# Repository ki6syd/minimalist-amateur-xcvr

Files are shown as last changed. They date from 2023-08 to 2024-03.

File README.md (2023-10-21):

 # minimalist-amateur-xcvr

Annotations (1) (1)

The radio hardware and user interface communicate with this API: https://app.swaggerhub.com/apis-docs/KI6SYD_1/MAX-3B/1.0.2

See http://max-3b.ki6syd.com for instructions on assembling the hardware and building firmware, in addition to background on the radio. The GitHub project just contains design files and code.

Software in this project is licensed under the GPLv3 License. https://www.gnu.org/licenses/quick-guide-gplv3.html

Hardware in this project is licensed under the TAPR Open Hardware License. https://tapr.org/the-tapr-open-hardware-license/

This project redistributes Ace.js, Copyright (c) 2010, Ajax.org B.V.

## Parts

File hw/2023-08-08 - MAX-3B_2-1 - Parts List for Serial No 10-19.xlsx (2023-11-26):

Item # | *Designator | *Qty | *Mfg Part # | *Package/Footprint
1 | C9, C10, C18, C22, C23, C25, C27, C28, C30, C33, C36, C40, C41, C42, C44, C51, C55, C56, C57, C58, C59, C62, C66, C68, C69, C82, C92, C93, C94, C98, C107, C153, C169, C170, C171, C172 | 36 | CC0201KRX5R5BB104 | 0201
2 | C11, C12, C19, C20, C24, C26, C34, C35, C43, C49, C54, C79, C84, C87, C91, C108, C109, C173, C178, C181, C182 | 21 | C0402C105K8PACTU | 0402
3 | R22, R25, R38, R39, R41, R44, R45, R46, R47, R48, R64, R74, R84, R88, R89, R93, R100, R102, R103 | 19 | CRCW020110K0FKED | 0201
4 | Q6, Q7, Q8, Q9, Q10, Q11, Q12, Q13, Q14, Q15, Q16, Q18, Q27, Q28, Q29, Q30, Q31 | 17 | DMN313DLT-7 | SOT-416
5 | C2, C3, C7, C8, C15, C16, C131, C132, C133, C134, C135, C136 | 12 | CGA3E1X7R1E105K080AC | 0603
6 | C17, C29, C64, C76, C77, C78, C88, C89, C90, C101, C141, C156 | 12 | C0402C102J5GACTU | 0402
7 | C127, C130, C145, C146, C147, C148, C149, C150, C151, C152 | 10 | C0402C270F5GACTU | 0402
8 | D9, D10, D11, D12, D13, D14, D16, D17, D18, D19 | 10 | NSR0240V2T1G | SOD-523
9 | R1, R2, R3, R10, R13, R16, R49, R94, R107, R119 | 10 | CRCW04020000Z0ED | 0402
10 | R12, R20, R30, R32, R62, R67, R72, R120, R121 | 9 | CRCW04021K00FKTD | 0402
11 | C37, C45, C112, C115, C119, C122, C126, C129 | 8 | GRM0335C1E100JA01D | 0201
12 | Q19, Q20, Q21, Q22, Q23, Q24, Q25, Q26 | 8 | 2N7002H6327XTSA2 | SOT-23
13 | R4, R5, R11, R19, R35, R69, R70, R85 | 8 | RC0402FR-0749K9L | 0402
14 | R21, R66, R73, R87, R91, R99, R117, R118 | 8 | CRGCQ0402F100K | 0402
15 | R108, R109, R110, R111, R112, R113, R114, R115 | 8 | CRCW04021R00FNED | 0402
16 | R23, R40, R42, R55, R134, R135, R136 | 7 | ERJ-2RKF1000X | 0402
17 | R26, R27, R28, R29, R33, R58, R61 | 7 | CRCW04025K10FKED | 0402
18 | RL1, RL2, RL3, RL4, RL5, RL6, RL7, RL8 | 8 | IM03CGR | IM RELAY GW
19 | C159, C160, C163, C167, C168, C186 | 6 | C0603C361J5GACTU | 0603
20 | C138, C139, C143, C144, C158 | 5 | C0603X681J5GACTU | 0603
21 | R36, R37, R56, R57, R65 | 5 | CRCW04024K70FKEDC | 0402
22 | C13, C14, C21, C86 | 4 | 865090140001 | 4.3MMx4.3MM
23 | C52, C53, C60, C65 | 4 | C0402C101J5GACTU | 0402
24 | C99, C100, C104, C106 | 4 | GRM1555C1H220GA01D | 0402
25 | C113, C116, C179, C180 | 4 | C0603C151J5GACTU | 0603
26 | L2, L3, L14, L15 | 4 | BLM21RK102SN1D | 0805
27 | R17, R18, R59, R60 | 4 | RC0805FR-10100RL | 0805
28 | R24, R90, R105, R116 | 4 | CRCW02011K00FNED | 0201
29 | R68, R79, R80, R101 | 4 | CR0402-FX-3302GLF | 0402
30 | U14, U15, U16, U17 | 4 | TSV852IQ2T | 8-UFDFN (2x2)
31 | C38, C39, C67 | 3 | CC0805KKX5R8BB106 | 0805
32 | C46, C47, C48 | 3 | CGA2B3X7R1V103K050BB | 0402
33 | C161, C162, C165 | 3 | VJ0603A471JXAAC | 0603
34 | D2, D4, D5 | 3 | PMEG2020AEA,115 | SOD-323
35 | Q1, Q2, Q17 | 3 | SI7101DN-T1-GE3 | PowerPAK1212-8
36 | C4, C5 | 2 | EEE-1EA220WR | 5.5MMx5.5MM
37 | C31, C32 | 2 | GRM033R71C391KA01D | 0201
38 | C61, C140 | 2 | C0603C222J5GACTU | 0603
39 | C70, C81 | 2 | C0402C332K4RACTU | 0402
40 | C73, C137 | 2 | CGA2B3X7R1H473K050BB | 0402
41 | C74, C75 | 2 | C0402C222J3GACTU | 0402
42 | C103, C105 | 2 | JR300 | 3.5MMx3.1mm
43 | C120, C123 | 2 | 04025A680JAT2A | 0402
44 | C154, C155 | 2 | 06035A561FAT2A | 0603
45 | C164, C166 | 2 | VJ0603A221JXACW1BC | 0603
46 | D1, D3 | 2 | PMEG3050EP,115 | SOD-128
47 | D6, D15 | 2 | BZX84C4V7LT1G | SOT-23
48 | J4, J5 | 2 | SJ1-3524N | SJ1-35
49 | Q4, Q5 | 2 | SMMBT3904WT1G | SOT-323
50 | R34, R122 | 2 | CRGCQ0402F22K | 0402
51 | R75, R76 | 2 | CRCW040236K0FKED | 0402
52 | R77, R78 | 2 | CRCW040247K0FKEDHP | 0402
53 | R83, R104 | 2 | AC0402FR-072K2L | 0402
54 | R125, R126 | 2 | CR0402-FX-4020GLF | 0402
55 | U2, U3 | 2 | LT1965IDD-3.3#PBF | 8-WFDFN (3x3)
56 | U10, U11 | 2 | PCF8574DGVR | 20-TFSOP
57 | U12, U13 | 2 | SN74LVC2G53DCUR | 8-VFSOP
58 | X1, X2 | 2 | ABM8G-26.000MHZ-B4Y-T | 3225
59 | C1 | 1 | C0603C474K4RACTU | 0603
60 | C50 | 1 | GJM1555C1H5R6BB01D | 0402
61 | C71 | 1 | GCM155R71E333KA55D | 0402
62 | C72 | 1 | 0402ZC393KAT2A | 0402
63 | C80 | 1 | C0402C681K3RACTU | 0402
64 | C110 | 1 | VJ0402D150JXCAJ | 0402
65 | C117 | 1 | GJM1555C1H6R0WB01D | 0402
66 | C124 | 1 | GJM1555C1H3R0BB01D | 0402
67 | D8 | 1 | NSVBAT54SWT1G | SOT-323
68 | J1 | 1 | 0733910320 | RP-SMA
69 | J2 | 1 | 0022286020 | 2x0.1IN
70 | J3 | 1 | USB4085-GF-A | USB-C
71 | J10 | 1 | 733910083 | SMA
72 | L1 | 1 | 7447785004 | WE-PD-XS
73 | L4 | 1 | LQM21FN100M70L | 0805
74 | L7 | 1 | 74437324220 | WE-LHMI-4020
75 | Q3 | 1 | PMDPB70XP,115 | 6-UFDFN (2x2)
76 | R31 | 1 | ERJ-2RKF2401X | 0402
77 | R43 | 1 | CRCW020112K0FNED | 0201
78 | R71 | 1 | RC0402FR-0710RL | 0402
79 | R81 | 1 | ERJ-2GEJ754X | 0402
80 | R82 | 1 | CRGCQ0402F470R | 0402
81 | R86 | 1 | AC0402FR-07220KL | 0402
82 | R92 | 1 | 3361P-1-103GLF | 3361P
83 | S1 | 1 | KSS221GLFS | KSS22
84 | U1 | 1 | LT3971IDD-5#PBF | 10-WFDFN (3x3)
85 | U4 | 1 | CYPD3177-24LQXQ | 24-UFQFN (4x4)
86 | U5 | 1 | LMV321LICT | SC-70-5
87 | U6 | 1 | ESP8266EX | 32-VFQFN (5x5)
88 | U7 | 1 | CP2102N-A02-GQFN28 | 28-WFQFN (5x5)
89 | U8 | 1 | W25Q32JVSSIQ | 8-SOIC
90 | U9 | 1 | SI5351A-B-GT | 10-MSOP
91 | U18 | 1 | PGA-103+ | SOT-89
92 | U21 | 1 | SN74ACT245PWR | 20-TSSOP
93 | U24 | 1 | PAM8302AASCR | 8-MSOP

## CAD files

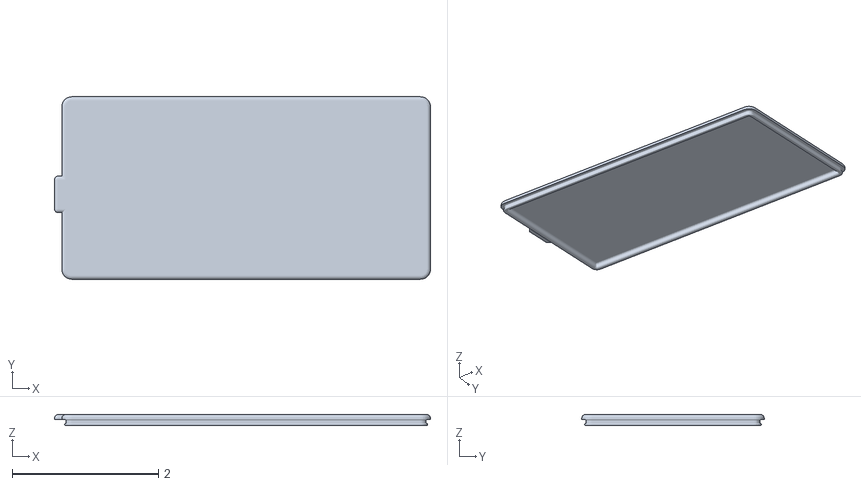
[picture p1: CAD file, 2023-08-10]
hw/3d printed case/2023-09-18 - MAX-3B Lid.stl
5.14 x 2.49 x 0.15

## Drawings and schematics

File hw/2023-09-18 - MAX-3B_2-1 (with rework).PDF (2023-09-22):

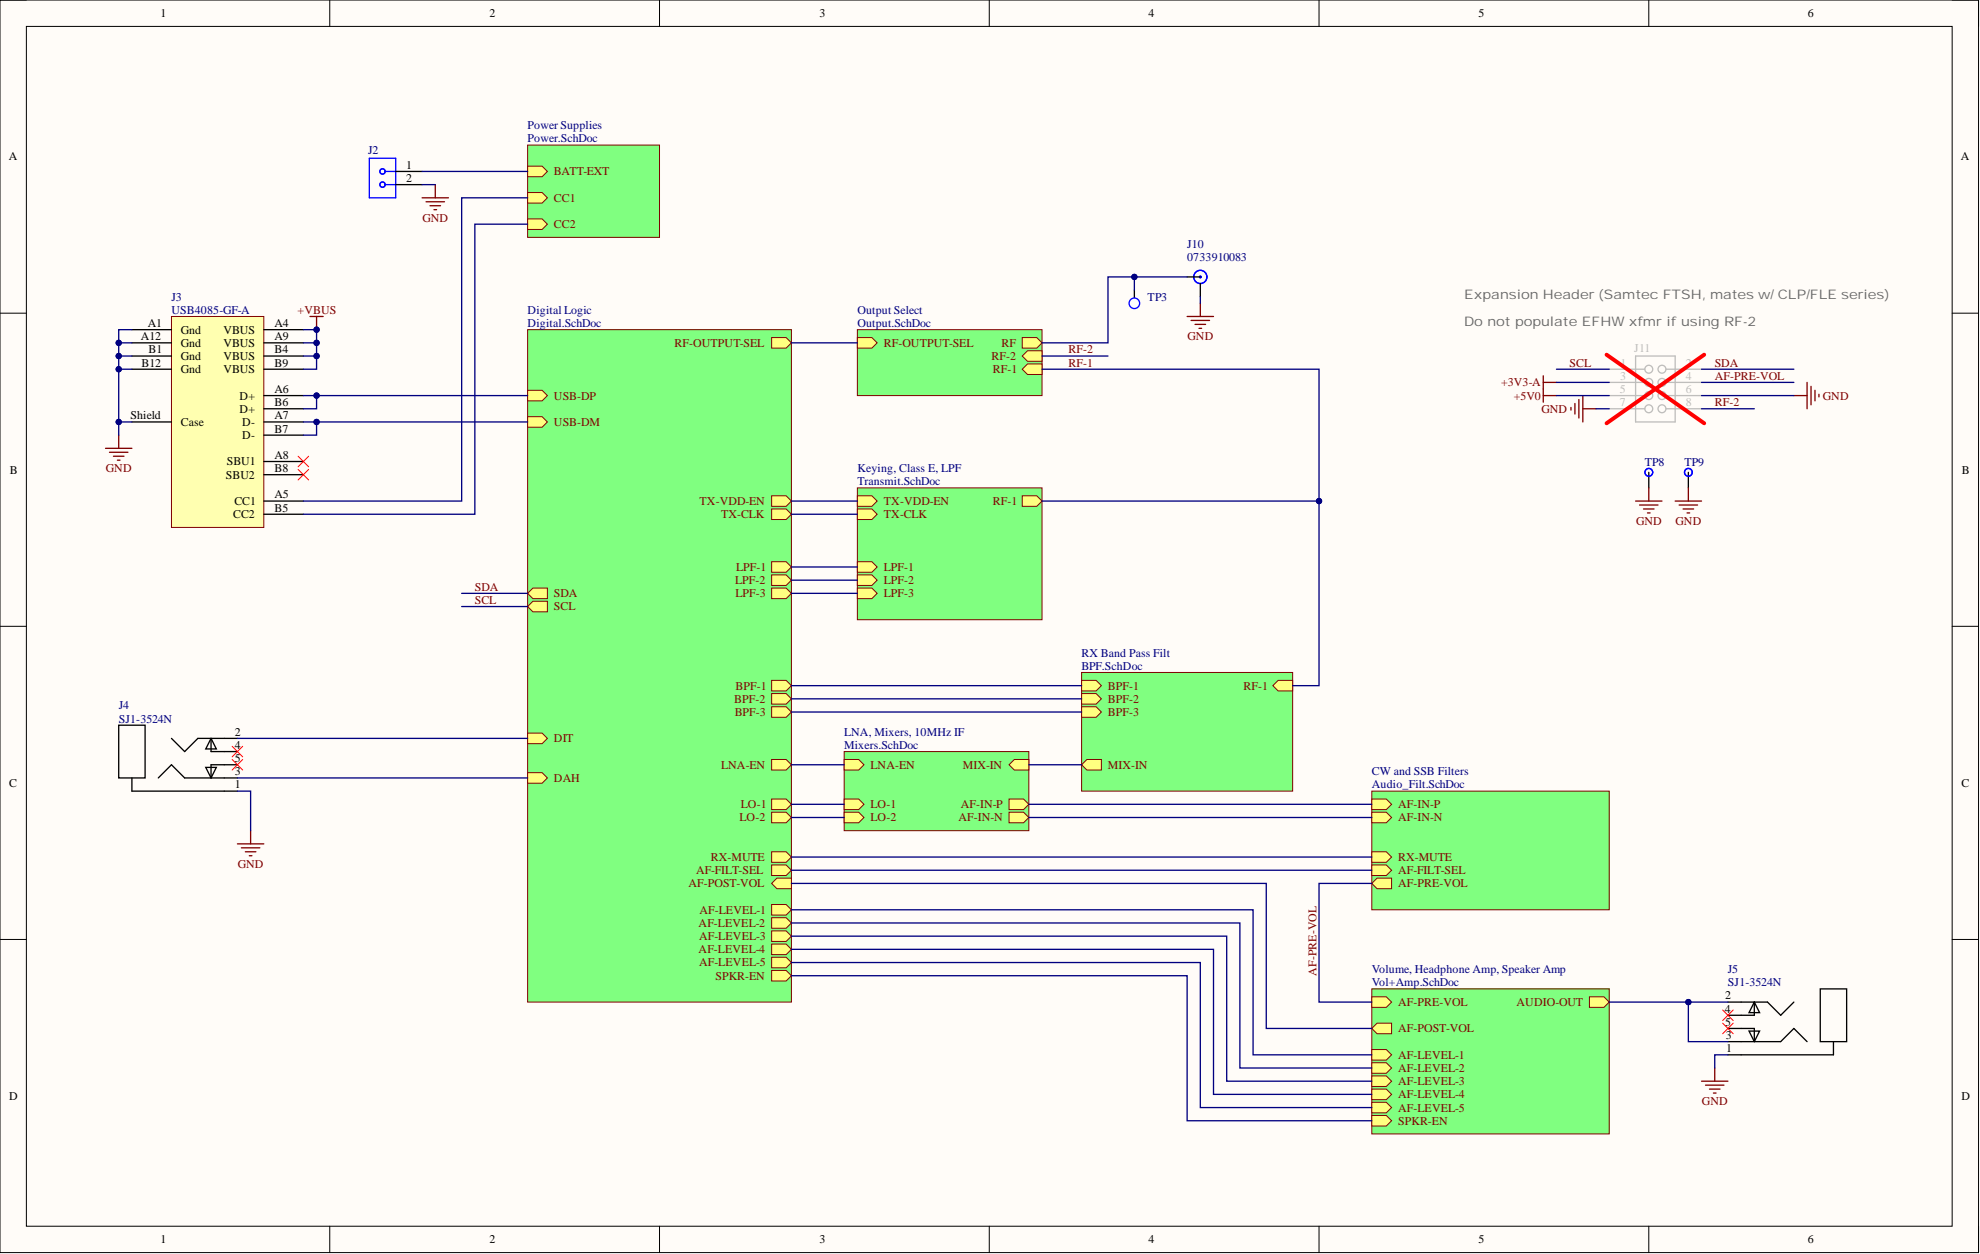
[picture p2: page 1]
Gnd B12; B7 Case Shield USB4085-GF-A J3; d SSB Fi; RX Ban; d Pas; BPF-2 LPF-1 LPF-2; 0MHz IF; wer Su; LPF-1 TX-V; LPF-2 LPF-3; g, Clas; t Selec; Expansion Header; Samtec FT; Amp, Speaker

Do not popula

te EFHW xfmr if using RF-2

AF-PRE-VOL

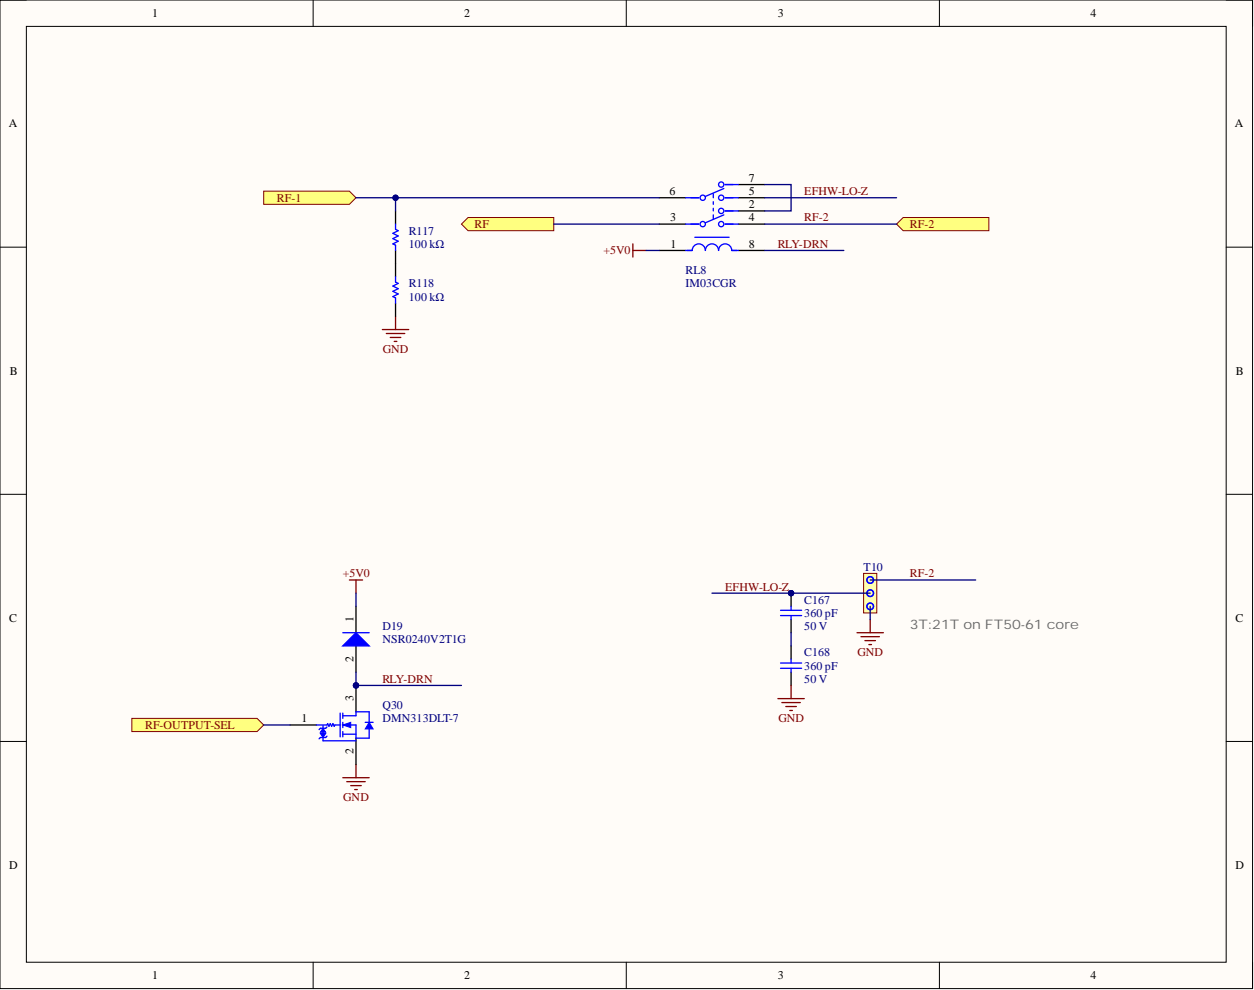
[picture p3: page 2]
RLY-DRN +5V0; 3T:21T on FT50-61 core

RF-OUTPUT-SEL

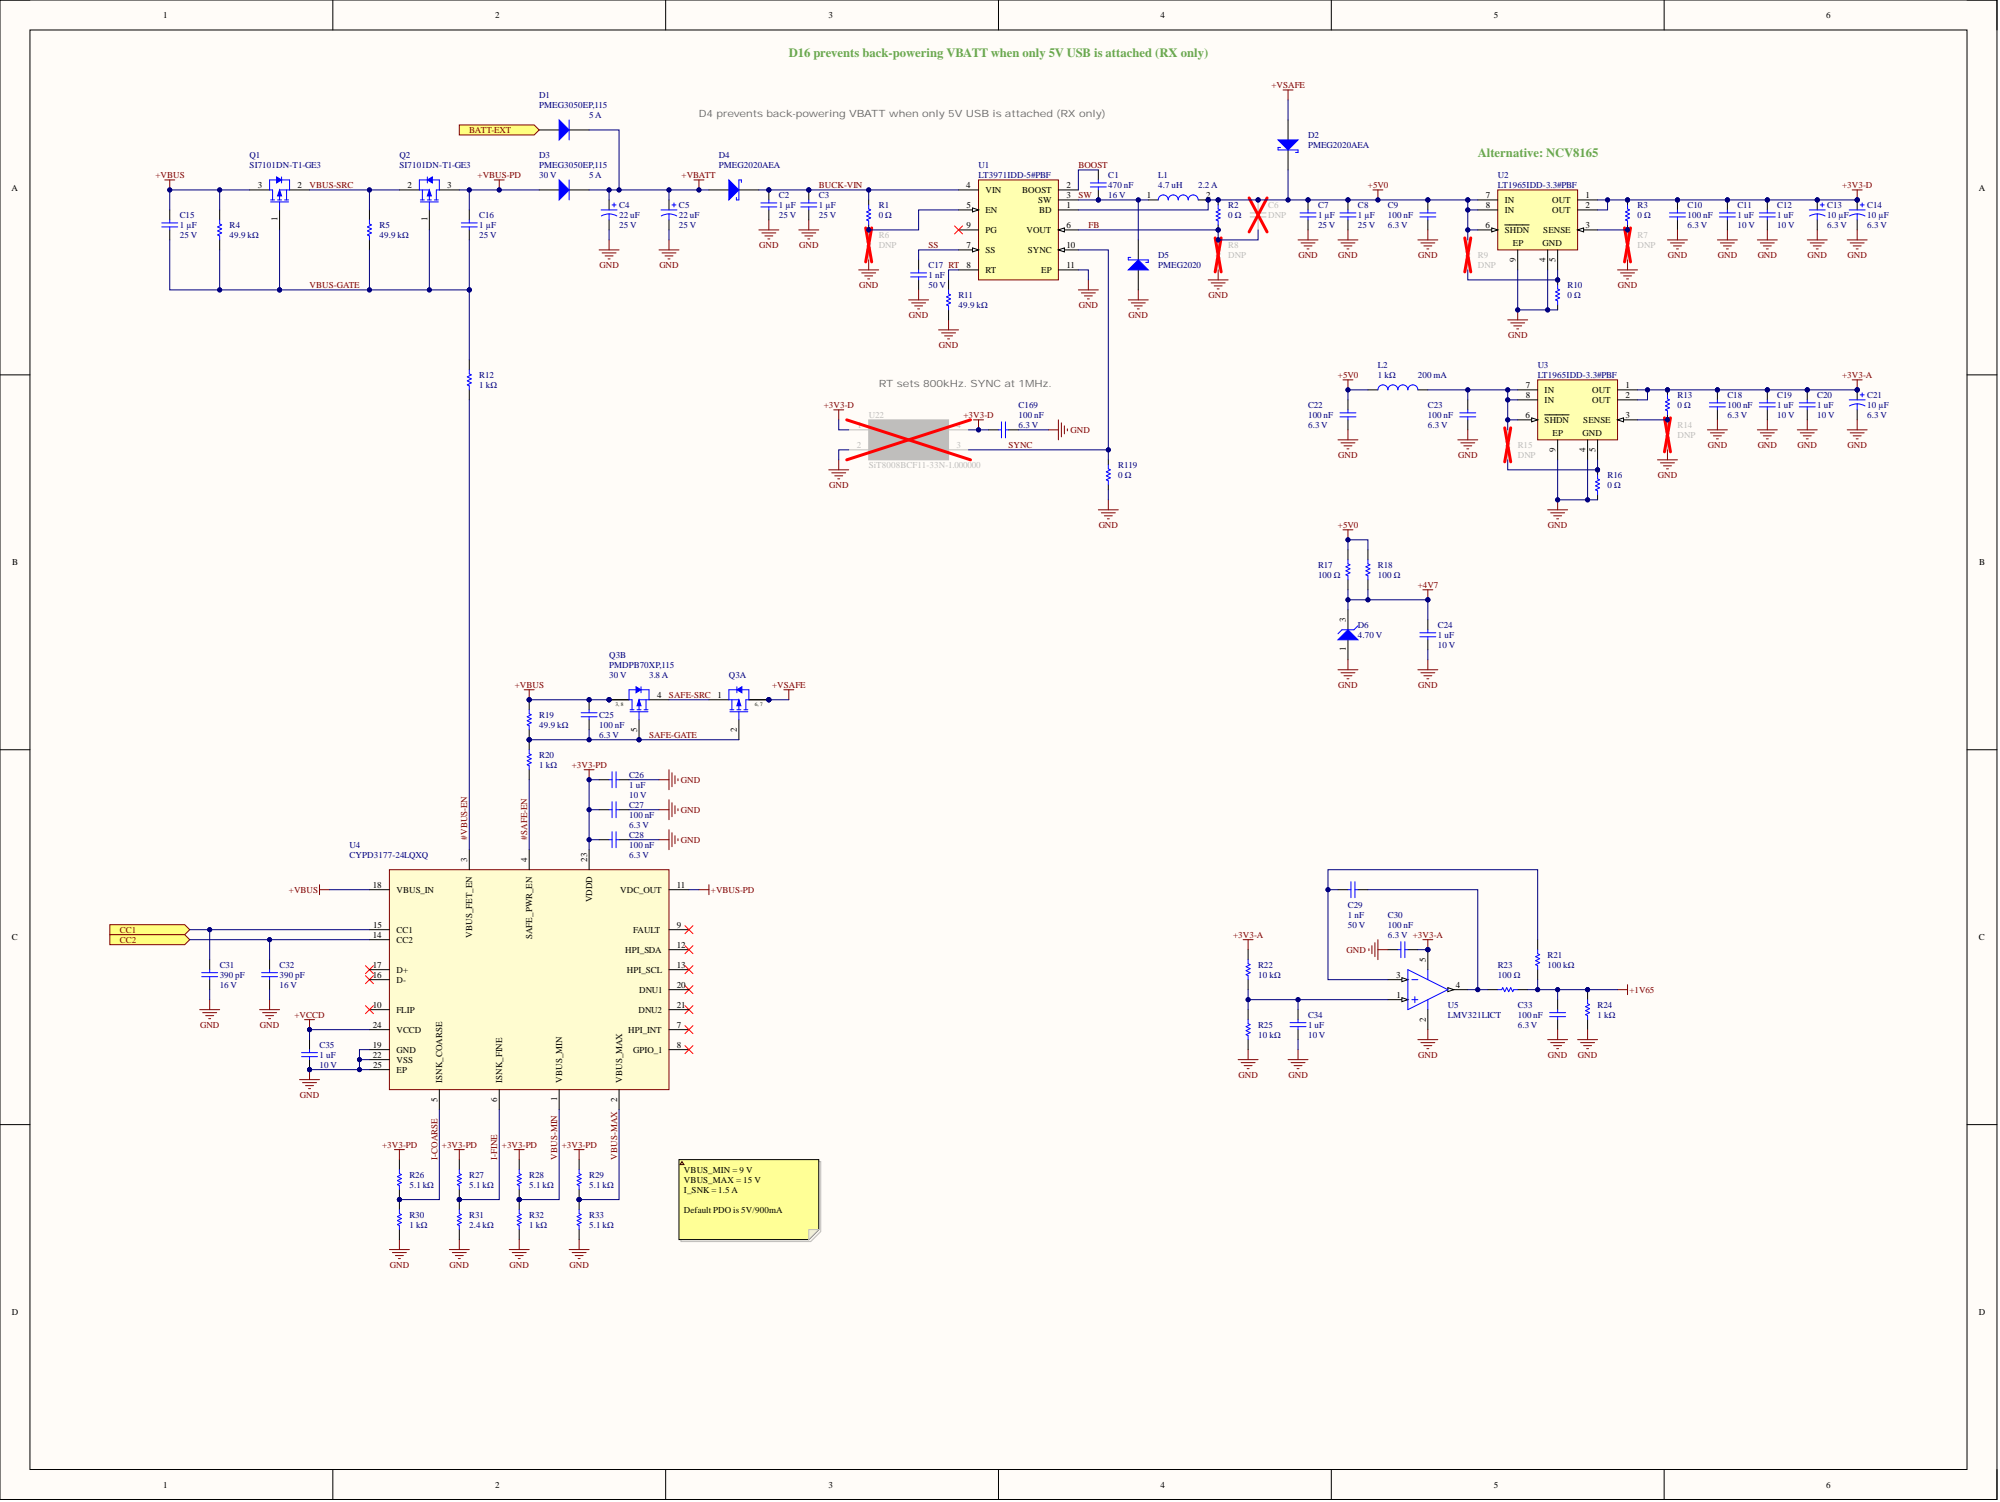
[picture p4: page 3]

D16 prevents back-powering VBATT when only 5V USB is attached (RX only)

D4 prevents back-powering VBATT when only 5V USB is attached (RX only)

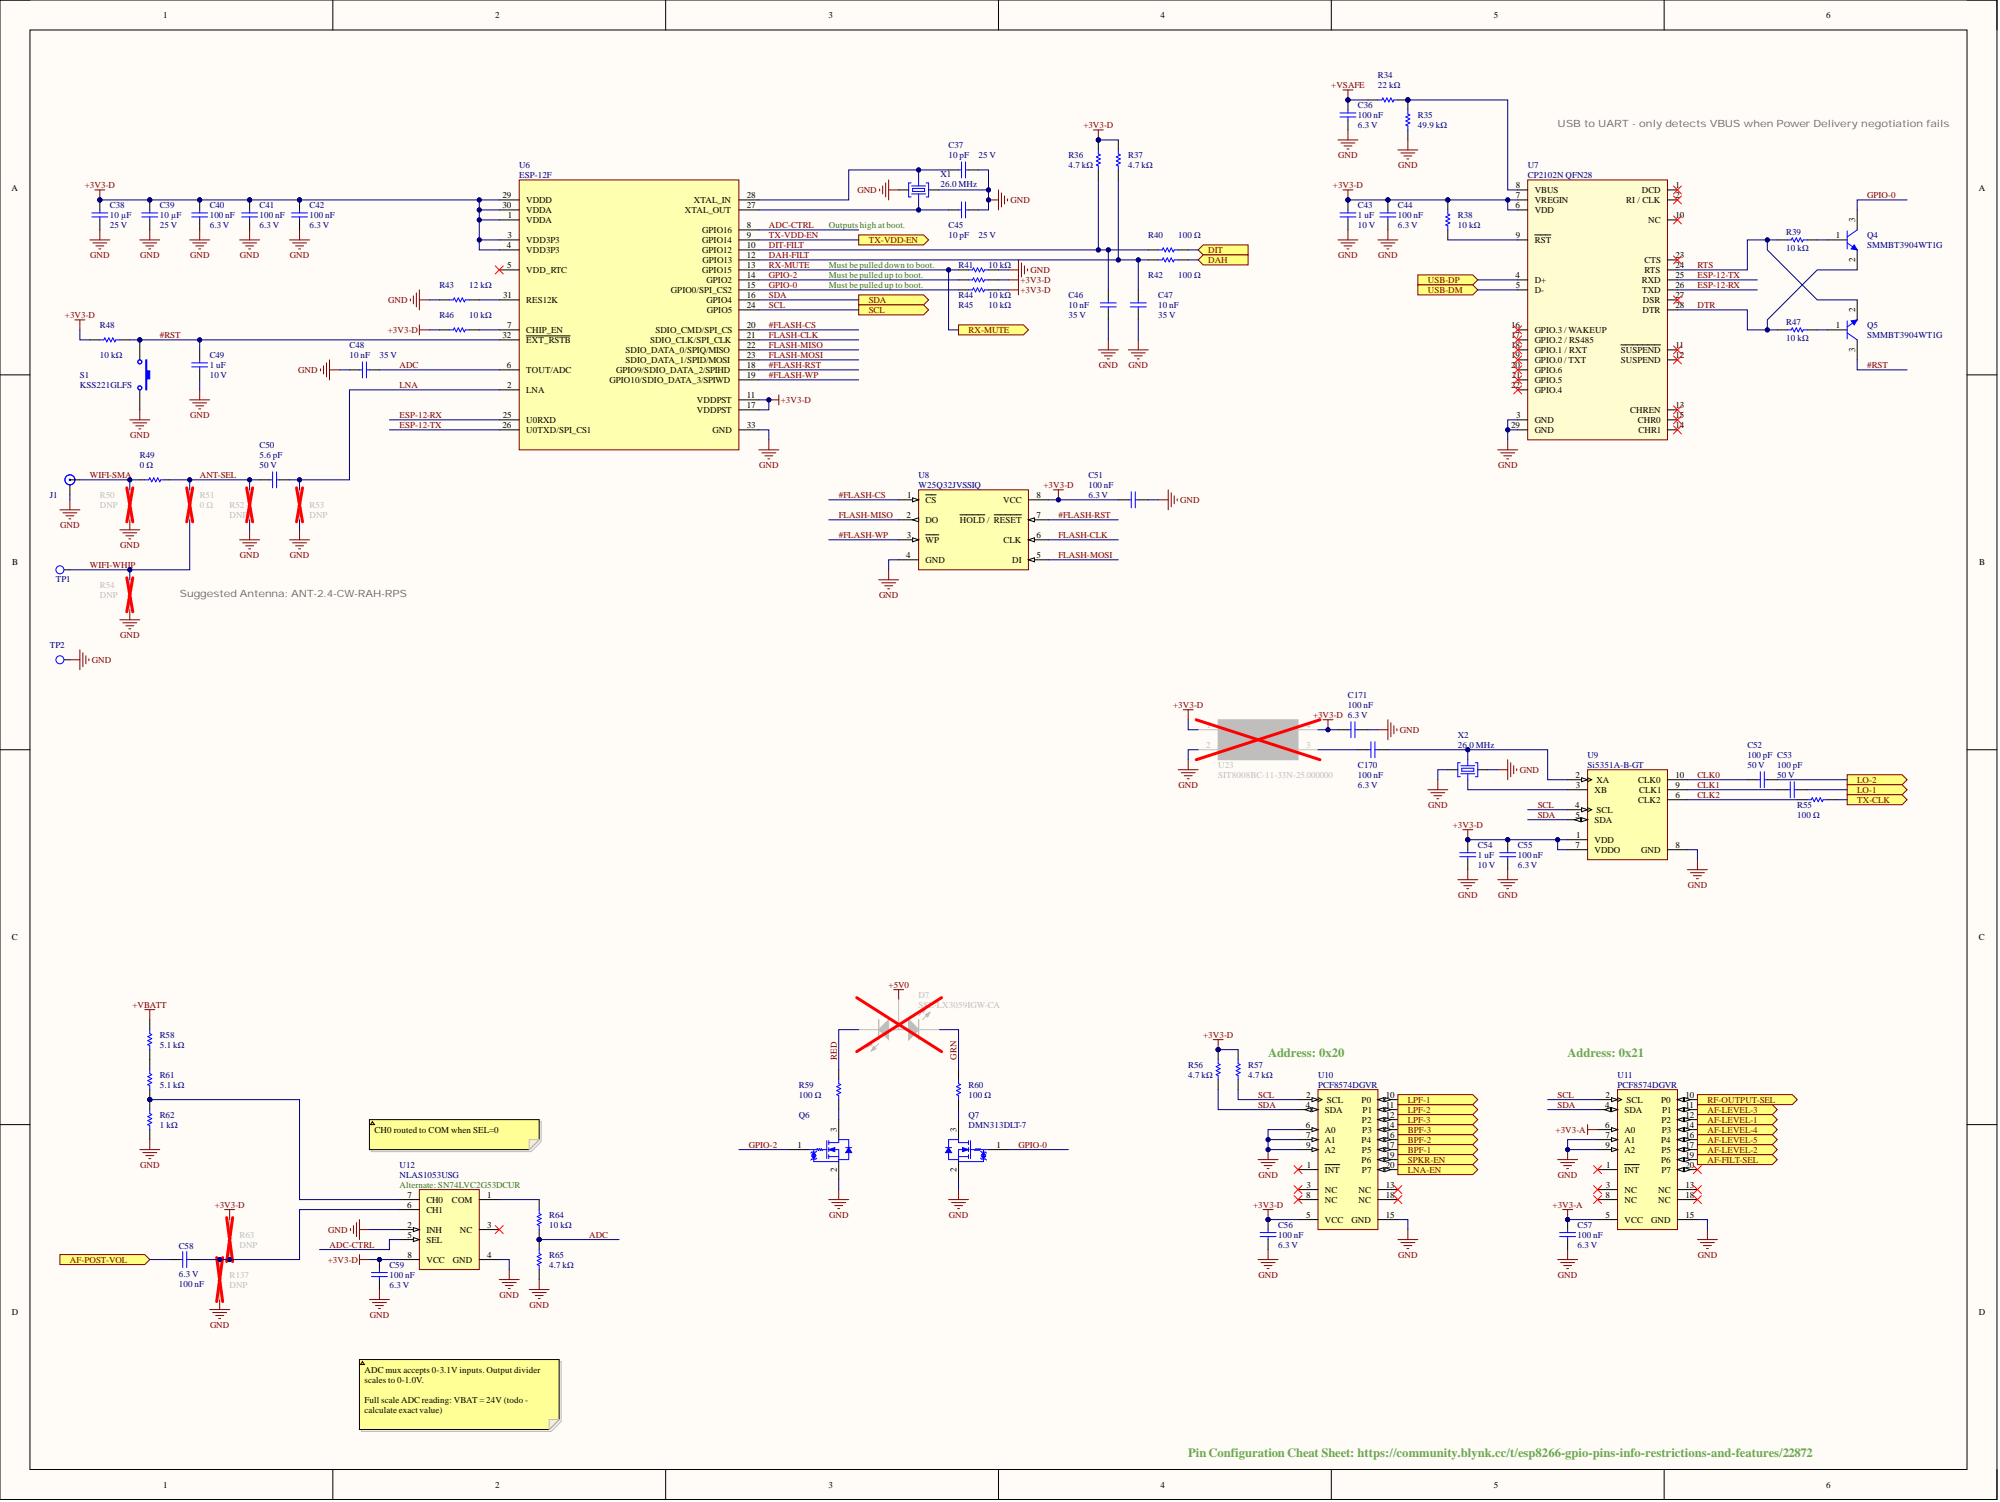
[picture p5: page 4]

USB to UART - only detects VBUS when Power Delivery negotiation fails

Must be pulled down to boot.
Must be pulled up to boot.

Suggested Antenna: ANT-2.4-CW-RAH-RPS

CH0 routed to COM when SEL=0

ADC mux accepts 0-3.1V inputs. Output divider
scales to 0-1.0V.

Full scale ADC reading: VBAT = 24V (todo -
calculate exact value)

Pin Configuration Cheat Sheet: https://community.blynk.cc/t/esp8266-gpio-pins-info-restrictions-and-features/22872

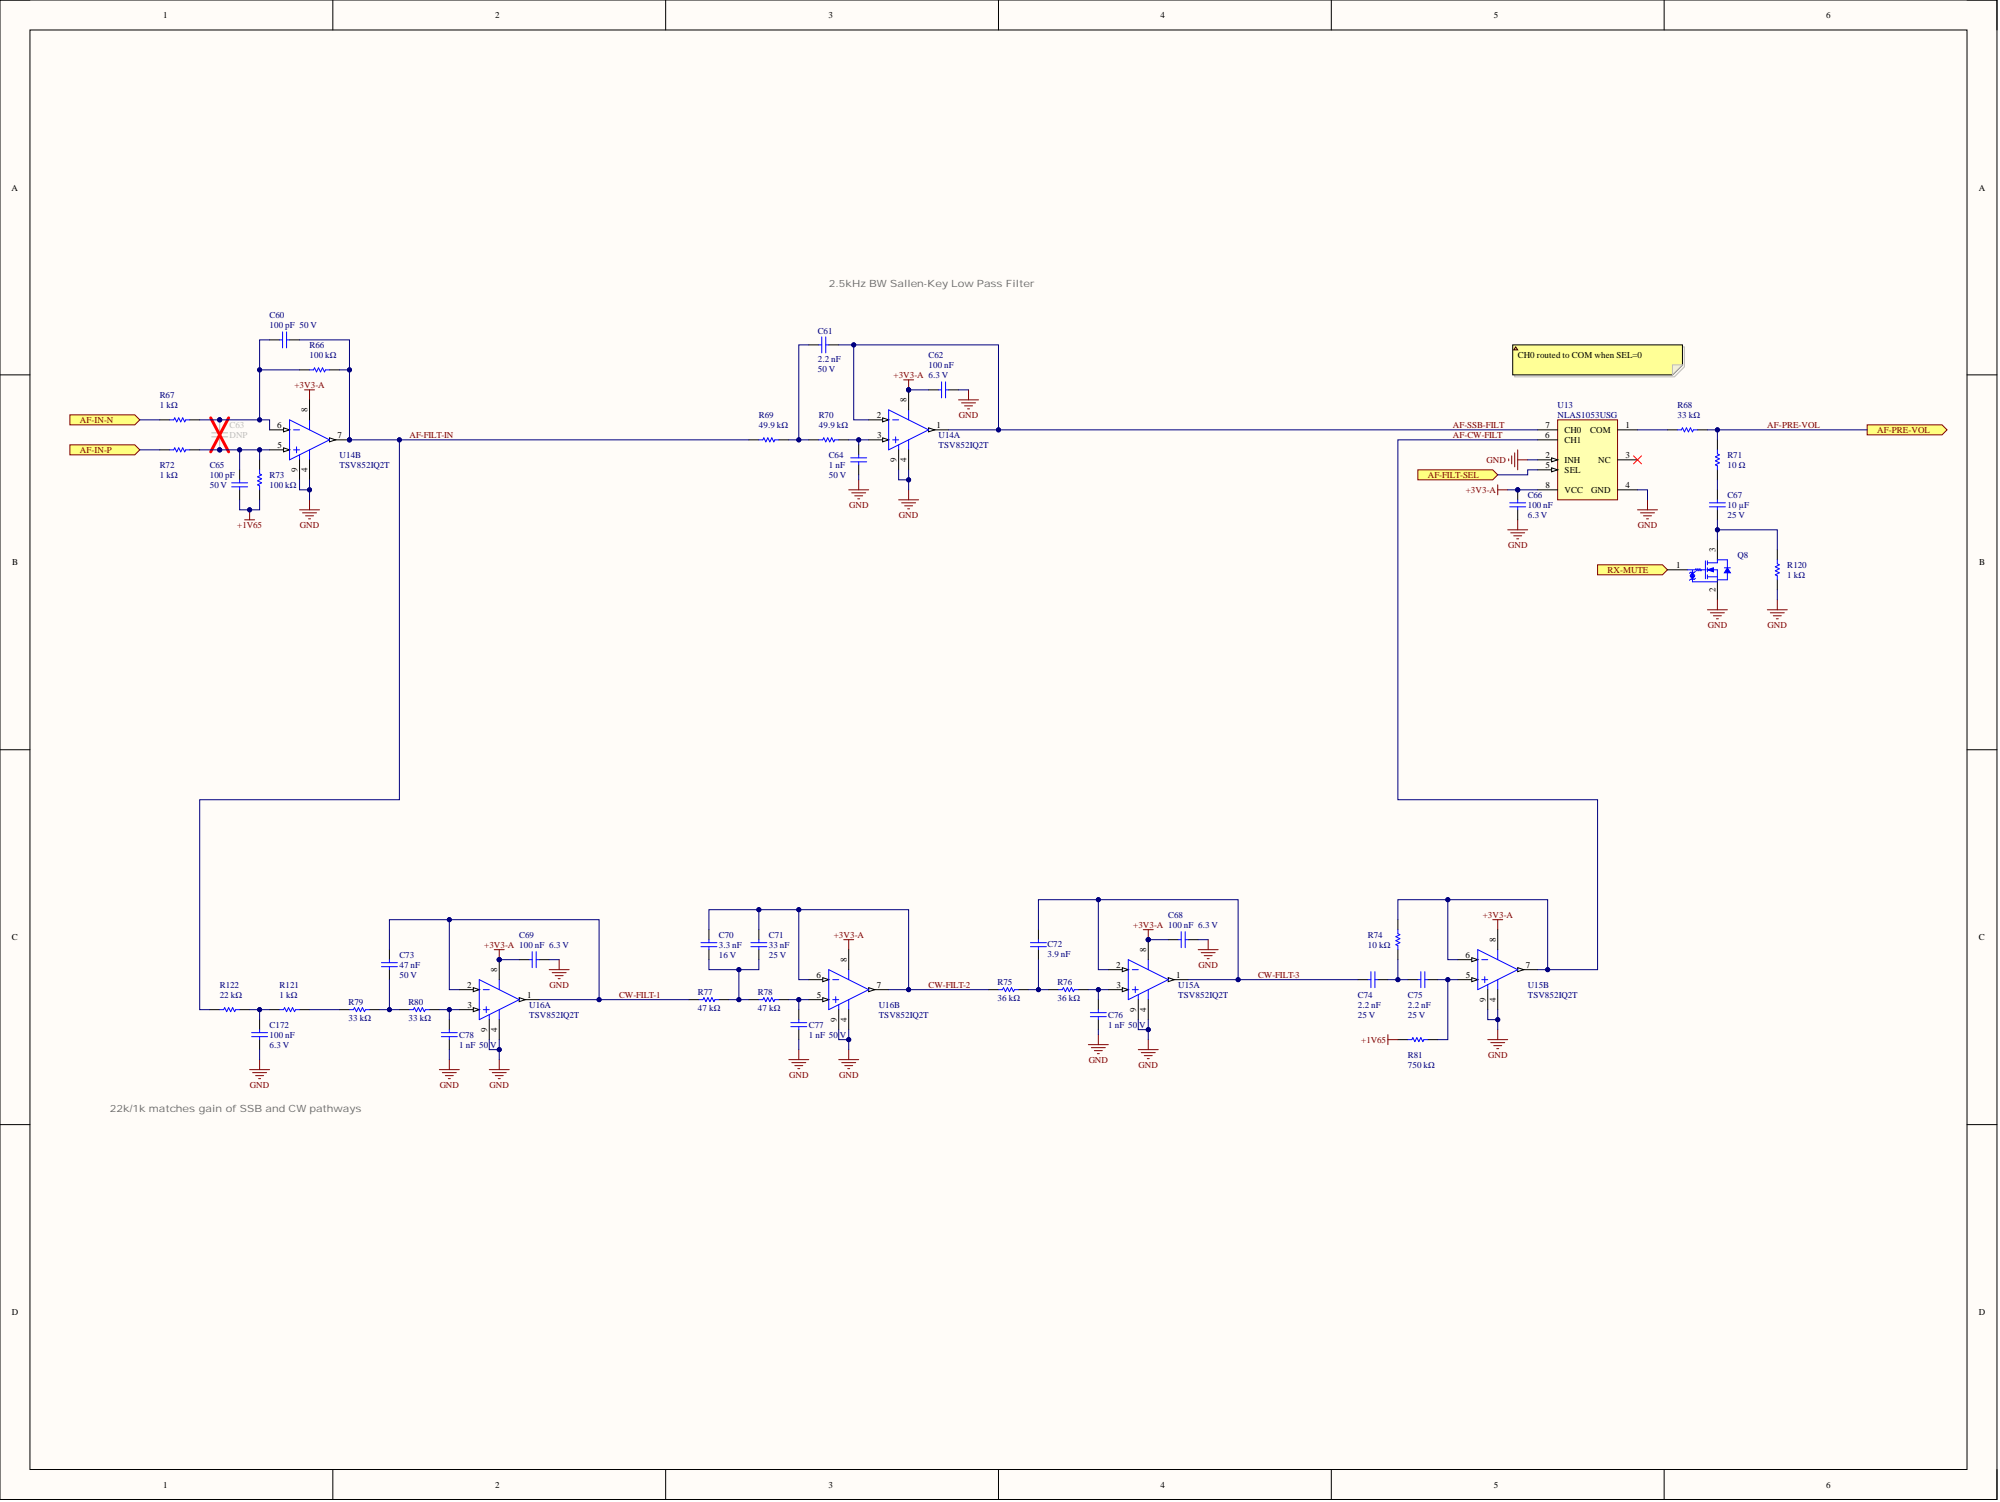
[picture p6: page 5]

2.5kHz BW Sallen-Key Low Pass Filter

CH0 routed to COM when SEL=0

AF-PRE-VOL AF-SSB-FILT
AF-CW-FILT

22k/1k matches gain of SSB and CW pathways

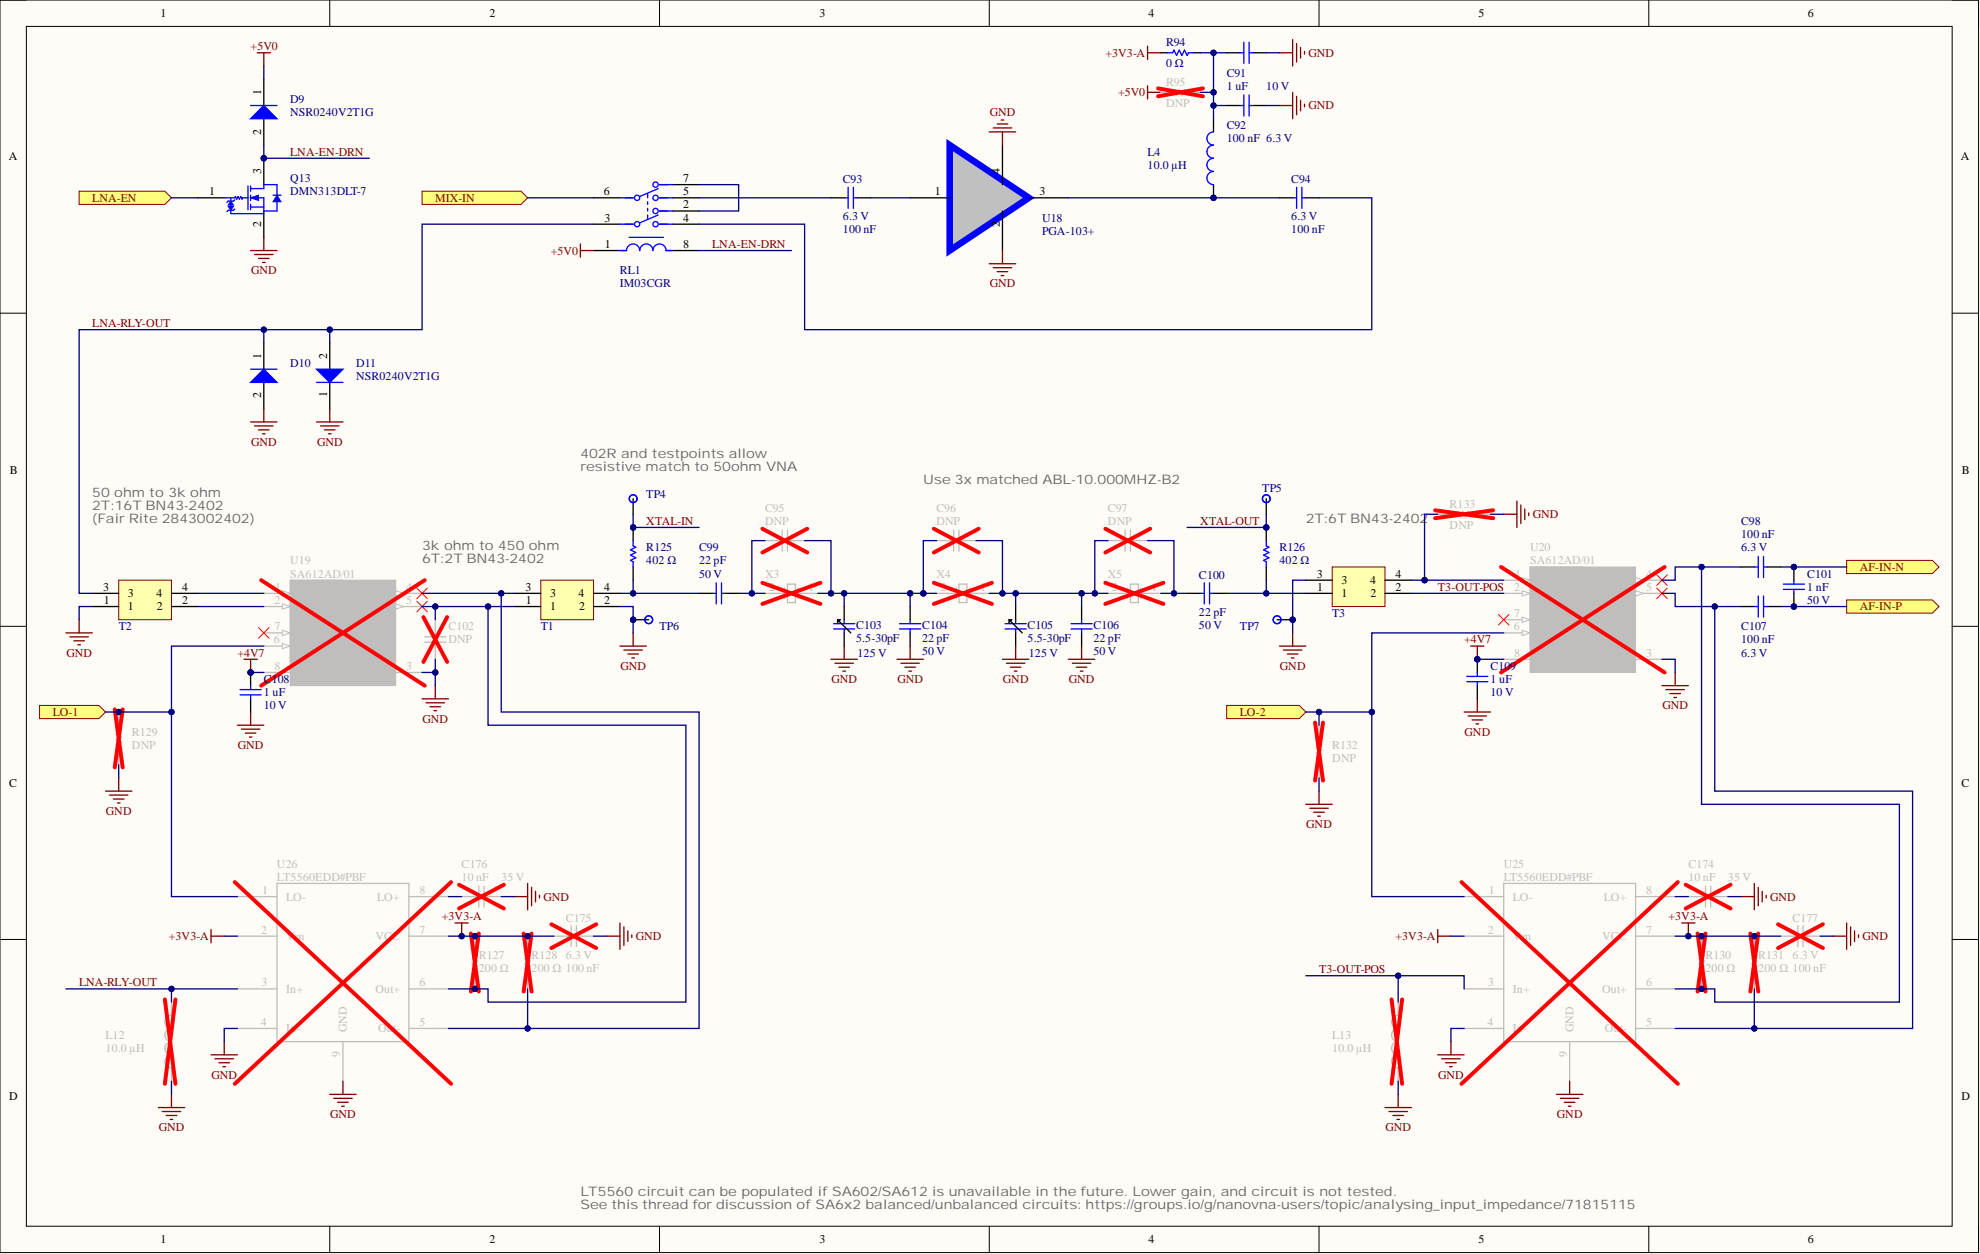
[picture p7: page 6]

402R and testpoints allow resistive match to 50ohm VNA

LT5560 circuit can be populated if SA602/SA612 is unavailable in the future. Lower gain, and circuit is not tested.
See this thread for discussion of SA6x2 balanced/unbalanced circuits: https://groups.io/g/nanovna-users/topic/analysing_input_impedance/71815115

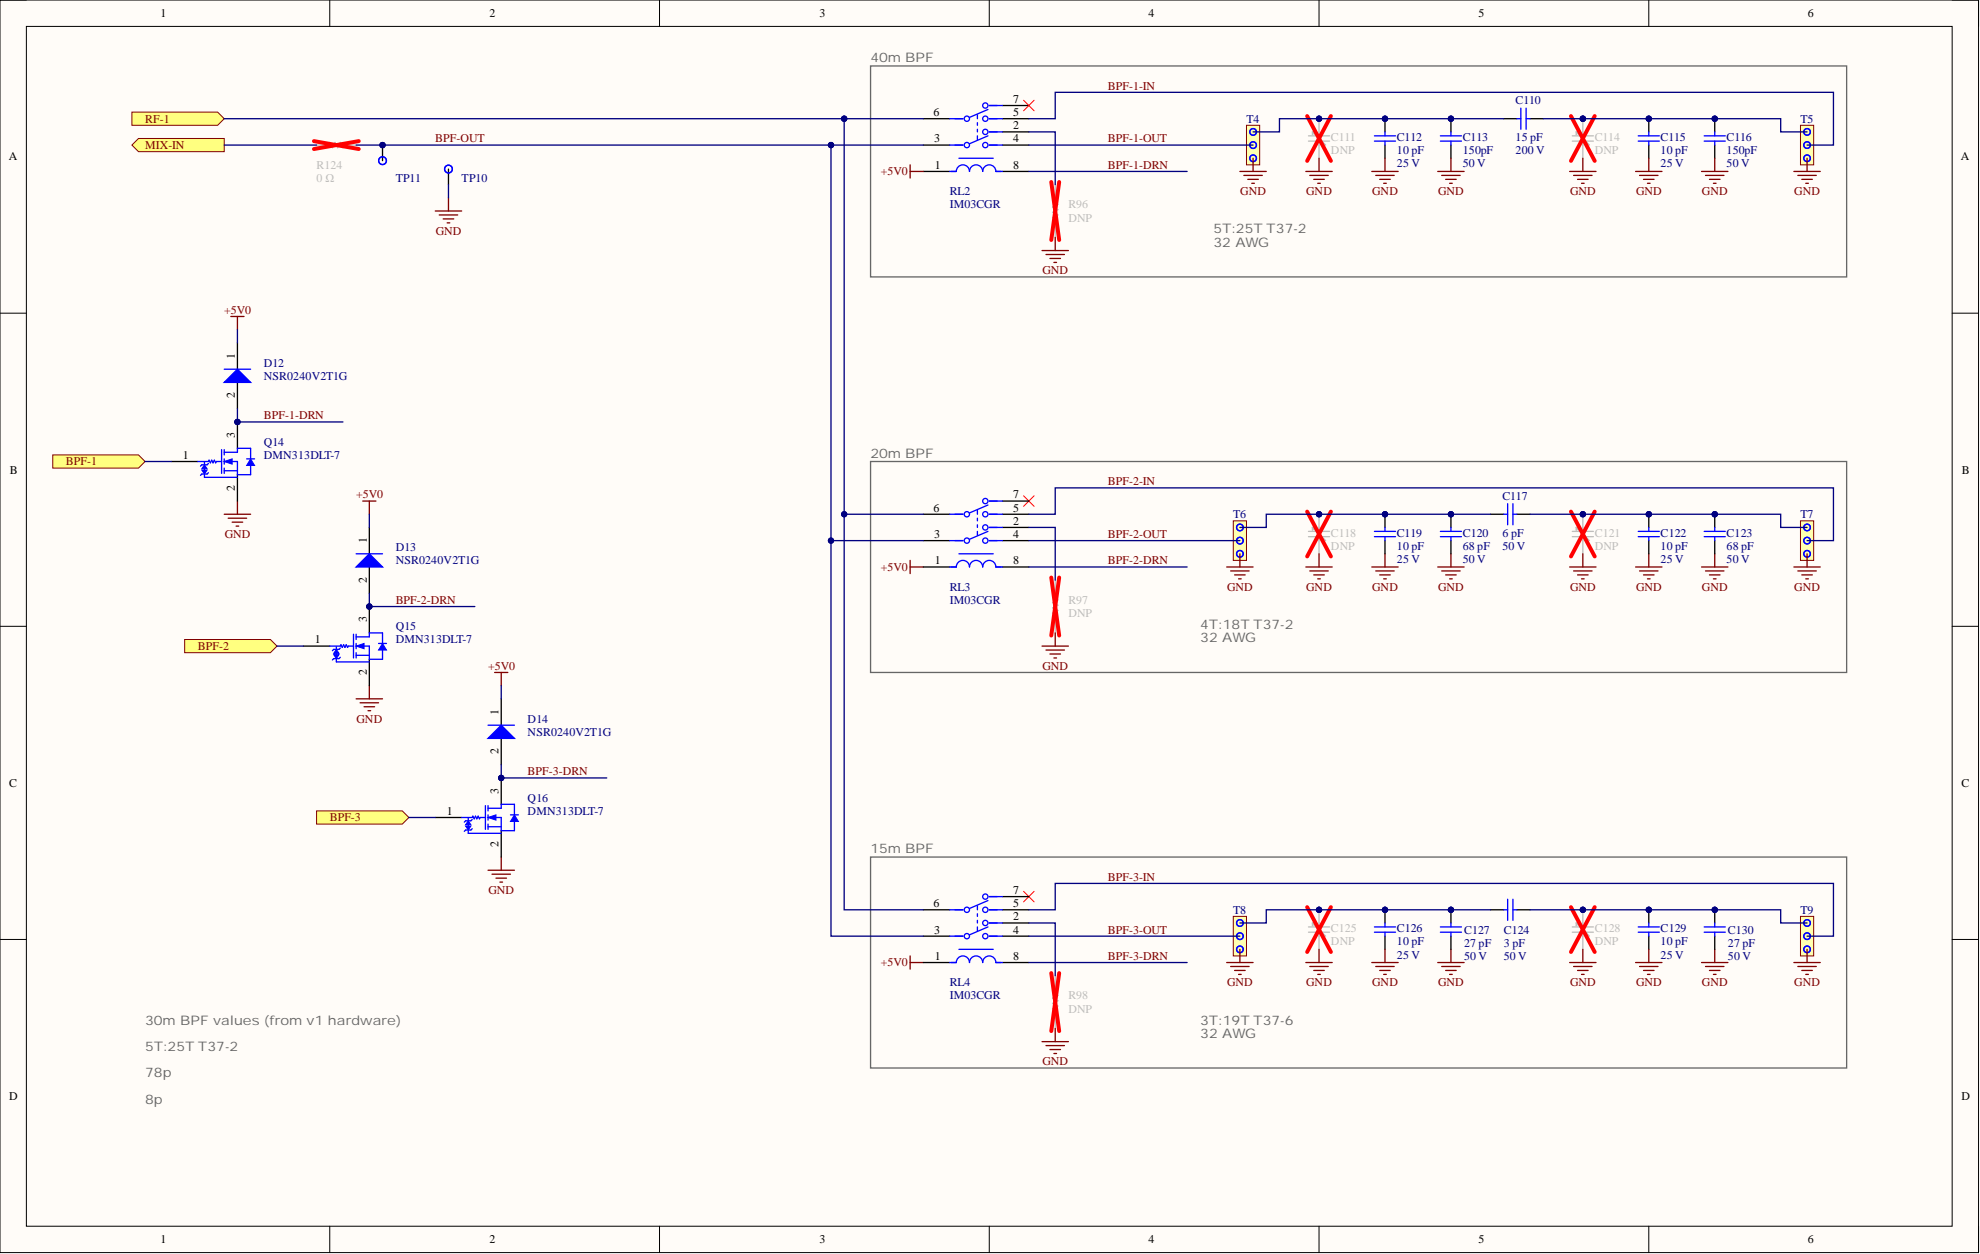
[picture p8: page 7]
PF values (; rom v1 hardware)

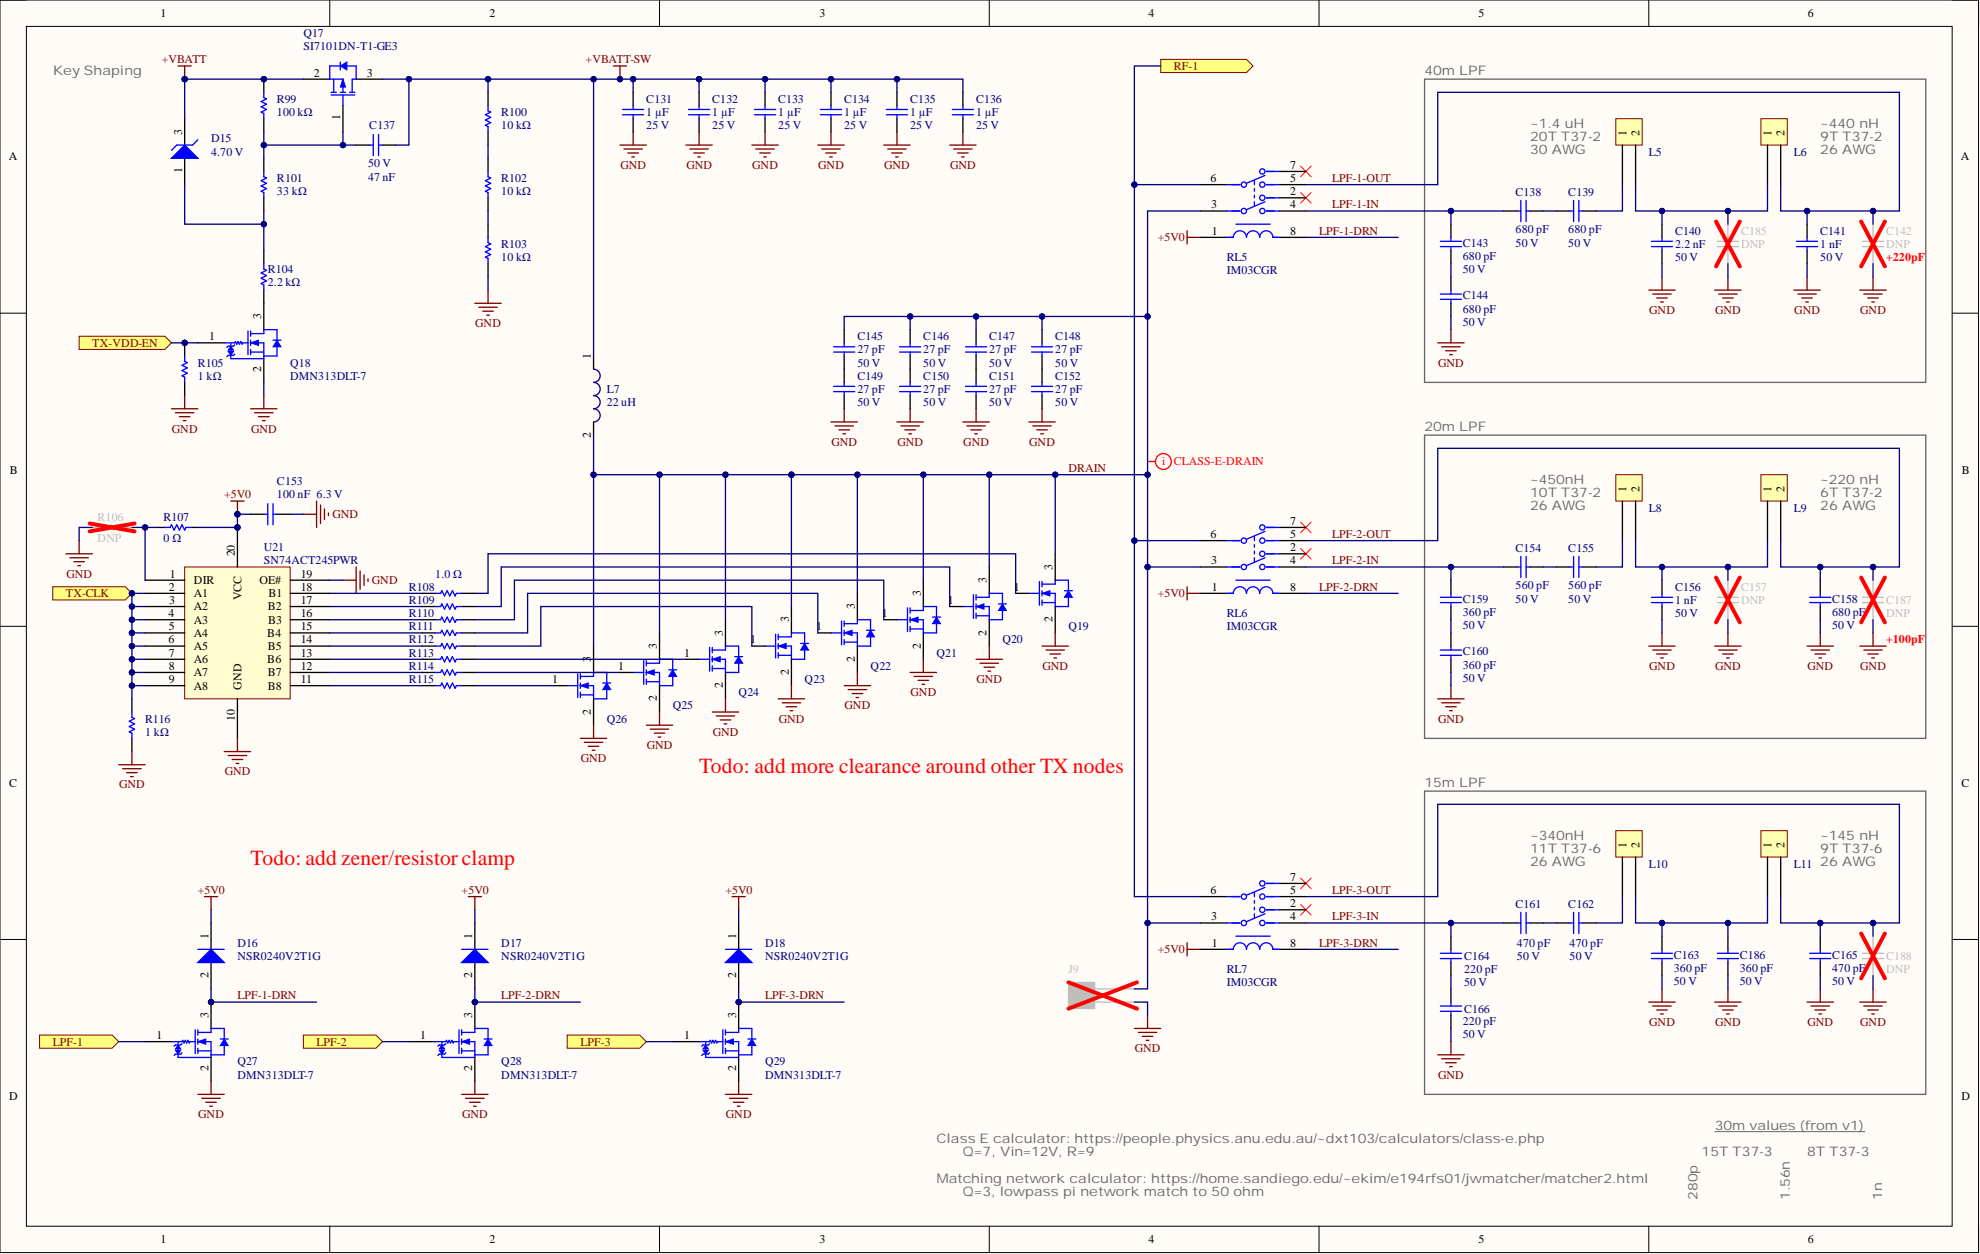
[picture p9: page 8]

GND
Todo: add more clearance around other TX nodes

Todo: add zener/resistor clamp

Class E calculator: https://people.physics.anu.edu.au/~dxt103/calculators/class-e.php
Q=7, Vin=12V, R=9

Matching network calculator: https://home.sandiego.edu/~ekim/e194rfs01/jwmatcher/matcher2.html
Q=3, lowpass pi network match to 50 ohm

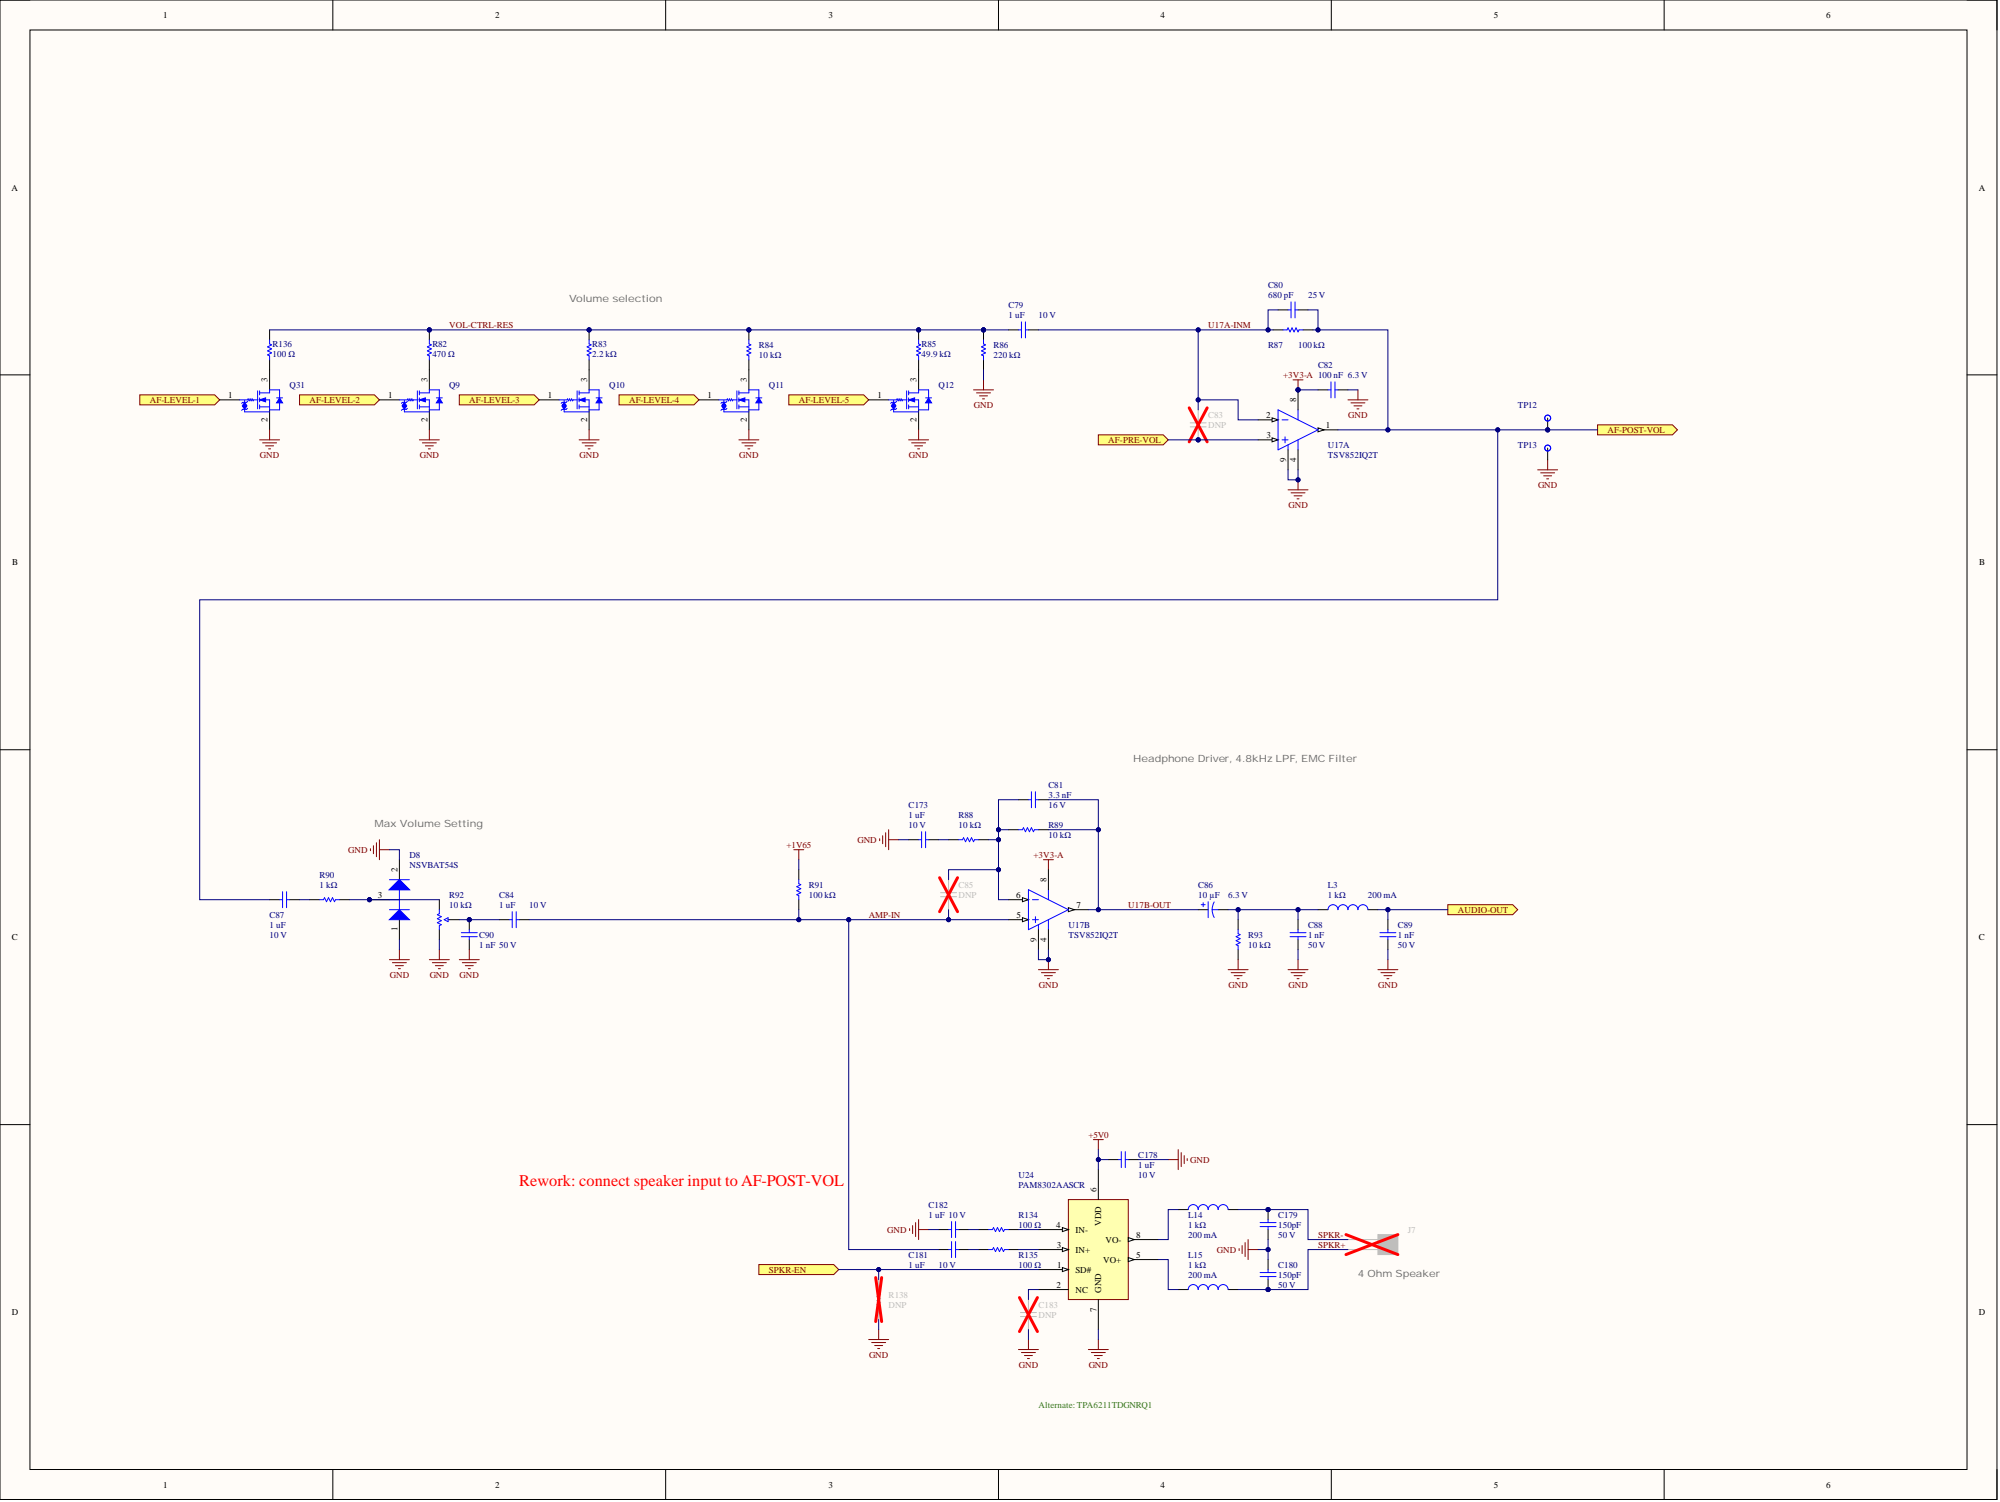
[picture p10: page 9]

Headphone Driver, 4.8kHz LPF, EMC Filter

Rework: connect speaker input to AF-POST-VOL

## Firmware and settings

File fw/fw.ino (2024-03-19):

// useful for flash use debug: "C:\Program Files (x86)\Arduino\hardware\tools\avr\bin\avr-nm.exe" --size-sort -C -r fw.ino.elf

#include <ESP8266WiFi.h>
// #include <ESPAsyncTCP.h>
#include <ESP8266mDNS.h>
#include <ESPAsyncWebServer.h>
#include <WiFiClient.h>
#include <ESP8266HTTPClient.h>
#include <Updater.h>
#include <SPIFFSEditor.h>
#include <ArduinoJson.h>
#include <Wire.h>
#include <PCF8574.h>
#include <si5351.h>
#include <JTEncode.h>
#include <TimeLib.h>
#include "git-version.h"
#include "Queue.h"
// TODO - create a Set/List/Array or similar class. Queue does not make sense for a lot of the usage here.
// something like: https://github.com/codebndr/DynamicArrayHelper-Arduino-Library/blob/master/DynamicArrayHelper.cpp

enum output_pin {
  OUTPUT_RX_MUTE,
  OUTPUT_TX_VDD_EN,
  OUTPUT_ADC_SEL,
  OUTPUT_GREEN_LED,
  OUTPUT_RED_LED,
  OUTPUT_LPF_1,
  OUTPUT_LPF_2,
  OUTPUT_LPF_3,
  OUTPUT_BPF_1,
  OUTPUT_BPF_2,
  OUTPUT_BPF_3,
  OUTPUT_AF_SEL_1,
  OUTPUT_AF_SEL_2,
  OUTPUT_AF_SEL_3,
  OUTPUT_AF_SEL_4,
  OUTPUT_BW_SEL,
  OUTPUT_LNA_SEL,
  OUTPUT_ANT_SEL,
  OUTPUT_SPKR_EN
};

enum input_pin {
  INPUT_VBAT,
  INPUT_AUDIO
};

// enums for output pin states - to help with clarity in situations like open drain outputs or high/low signal driving a relay
enum output_state {
  OUTPUT_HIGH,
  OUTPUT_LOW,
  OUTPUT_ON,
  OUTPUT_OFF,
  OUTPUT_SEL_VBAT,
  OUTPUT_SEL_AUDIO,
  OUTPUT_SEL_CW,
  OUTPUT_SEL_SSB,
  OUTPUT_MUTED,
  OUTPUT_UNMUTED,
  OUTPUT_ANT_DIRECT,
  OUTPUT_ANT_XFMR,
};

enum qsk_state_type {
  MODE_RX,
  MODE_TX,
  MODE_QSK_COUNTDOWN
};

enum sk_state_type {
  MODE_SK_FALLING,
  MODE_SK_DOWN,
  MODE_SK_RISING,
  MODE_SK_UP
};


enum key_type {
  KEY_STRAIGHT,
  KEY_PADDLE
};

enum digital_message_type {
  MODE_CW,
  MODE_FT8,
  MODE_WSPR
};

const char * preference_file = "/preferences.json";
const char * wifi_file = "/wifi_info.json";
const char * hardware_file = "/hardware_info.json";
const char * beacon_file = "/beacon.json";
const char * capability_file = "/capability.json";
String api_base_url = "/api/v1/";
const int led = LED_BUILTIN;

AsyncWebServer server(80);
HTTPClient http;
WiFiClient client;
Si5351 si5351;
JTEncode jtencode;
PCF8574 pcf8574_20(0x20);
PCF8574 pcf8574_21(0x21);

// ------------------------------ time variables ------------------------------
uint64_t time_offset = 0;

// ------------------------------ queue variables -----------------------------
bool keyer_abort = false;
// todo: use a more reasonable buffer length
struct DigitalMessage {
  digital_message_type type;
  bool ignore_time;
  uint64_t freq;
  uint8_t buf[255];
};

#define DIGITAL_QUEUE_LEN   8
Queue<DigitalMessage> digital_queue(DIGITAL_QUEUE_LEN);

#define BEACON_FREQ_LIST_LEN    8
String beacon_mode = "false";
bool beacon = false;
uint32_t beacon_interval = 1000*60*60;  // milliseconds
uint64_t last_beacon = 0;
Queue<uint64_t> beacon_freqs(BEACON_FREQ_LIST_LEN);


struct BandCapability {
  uint8_t band_num;
  uint64_t min_freq;
  uint64_t max_freq;
  String tx_modes[4];
  String rx_modes[4];
};

#define BAND_CAPABILITY_LIST_LEN  5
Queue<BandCapability> bands(BAND_CAPABILITY_LIST_LEN);


// flag_freq indicates whether frequency OR rx bandwidth need to change
bool flag_freq = false, flag_vol = true, flag_special = false;
bool dit_flag = false, dah_flag = false, sk_flag = false;

String ip_address = "No IP";

qsk_state_type tx_rx_mode = MODE_QSK_COUNTDOWN;
sk_state_type sk_mode = MODE_SK_UP;
int64_t qsk_counter = 0;

// used in OTA
size_t content_len;

// used in io
String hardware_rev = "";
String unit_serial = "";

// TODO: a few of these shouldn't be uint16_t's, figure out better enum strategy
uint16_t rx_bw = OUTPUT_SEL_CW;
uint16_t ant = OUTPUT_ANT_DIRECT;
uint16_t qsk_period = 500;
uint16_t keyer_speed = 0;
uint16_t vol = 0;
int16_t mon_offset = 0;
uint16_t special = 0;
// TODO: turn this into an enum
bool lna_state = false;
bool speaker_state = false;
key_type key = KEY_PADDLE;
output_pin lpf_relay = OUTPUT_LPF_1, bpf_relay = OUTPUT_BPF_1;

bool allow_tx = true;

float last_vbat = 0, last_smeter = 0;
float min_vbat, max_vbat;

// TODO: replace f_rf with a concept of dial frequency, and USB/LSB
uint64_t f_rf = 0;
uint64_t f_bfo = 0;
uint64_t f_audio = 0;
uint64_t f_vfo = 0;
uint64_t f_if = 0;

uint16_t keyer_min = 0;
uint16_t keyer_max = 0;
uint16_t vol_min = 0;
uint16_t vol_max = 0;

// TODO - restructure init functions so there's one batch read from JSON before configuring hardware
void setup(void) {
  // short delay to make sure serial monitor catches everything
  // my_delay(2000);

  Serial.begin(115200);
  SPIFFS.begin();

  // comment in for ESP module debug
  // Serial.setDebugOutput(true);

  init_gpio();
  init_audio();
  gpio_write(OUTPUT_GREEN_LED, OUTPUT_ON);

  // start up wifi and MDNS
  // looks for home network, start AP if it's not found
  init_wifi_mdns();

  // start web server, attach handlers
  init_web_server();

  // start radio hardware
  init_radio();

  // start keyer
  init_keyer();

  // turn off TX power
  gpio_write(OUTPUT_TX_VDD_EN, OUTPUT_OFF);

  // set antenna impedance relay
  if(load_json_config(preference_file, "ant_default") == "OUTPUT_ANT_DIRECT")
    ant = OUTPUT_ANT_DIRECT;
  if(load_json_config(preference_file, "ant_default") == "OUTPUT_ANT_XFMR")
    ant = OUTPUT_ANT_XFMR;
  gpio_write(OUTPUT_ANT_SEL, (output_state) ant);

  // set lna option
  if(load_json_config(preference_file, "lna_default") == "ON") {
    lna_state = true;
    gpio_write(OUTPUT_LNA_SEL, OUTPUT_ON);
  }
  else {
    lna_state = false;
    gpio_write(OUTPUT_LNA_SEL, OUTPUT_OFF);
  }    

  // TODO - bulk read from JSON, move everything out of init files
  min_vbat = load_json_config(preference_file, "v_bat_min_cutoff").toFloat();
  max_vbat = load_json_config(preference_file, "v_bat_max_cutoff").toFloat();

  qsk_period = load_json_config(preference_file, "qsk_delay_ms").toFloat();
  mon_offset = load_json_config(preference_file, "sidetone_level").toFloat();

  if(load_json_config(preference_file, "allow_tx") == "false")
    allow_tx = false;

  unit_serial = load_json_config(hardware_file, "serial_number");

  // start the beacon module
  init_beacon();

  // initial read of battery voltage
  last_vbat = analog_read(INPUT_VBAT);
}


void loop(void) {
  uint8_t i = 0;
  
  // handle paddle and key inputs
  // continue after dit or dah to skip other checks. Minimizes delay if there's another key press immediately
  if(key == KEY_PADDLE) {
    // empty the queue so touching the key stops ongoing messages
    if(dit_flag || dah_flag)
      empty_digital_queue();
      
    if(dit_flag) {
      dit();
      return;
    }
    else if(dah_flag) {
      dah();
      return;
    }
  }
  if(key == KEY_STRAIGHT) {
    // interrupt sets this flag
    if(sk_flag) {
      if(sk_mode == MODE_SK_DOWN) {
        key_on();
      }
      if(sk_mode == MODE_SK_UP) {
        key_off();
      }
      
      // clear the flag
      sk_flag = false;

      // start looking at pins again
      attach_sk_isr(true);

      empty_digital_queue();
    }
    // poll to make sure we haven't missed an interrupt (hack...)
    if(sk_mode == MODE_SK_DOWN && digitalRead(12) == 1) {
      key_off();
      sk_mode = MODE_SK_UP;
      attach_sk_isr(true);
    }
    if(sk_mode == MODE_SK_UP && digitalRead(12) == 0) {
      key_on();
      sk_mode = MODE_SK_DOWN;
      attach_sk_isr(true);
    }
  }
  

  // reconfig clocks if frequency has changed
  // don't update frequency if we are still in TX mode - derisks hardware damage
  if(flag_freq) {
    change_freq();
  }

  // perform volume update if change detected
  if(flag_vol) {
    flag_vol = false;
    update_volume(vol);
  }

  // take action based on special debug functions
  if(flag_special) {
    flag_special = false;
    special_mode(special);
  }

  // run beacon logic if necessary
  if(beacon) {
    update_beacon();
  }

  // handle any digital modes queue entries (CQ, FT8, WSPR)
  if(digital_queue.count() > 0) {
    service_digital_queue();
  }
  
  // decrement QSK timer if needed
  update_qsk_timer();

  // do analog read once per loop. vbat during tx, smeter during rx. 
  // noise comes from toggling adc mux, so reading both types doesn't work well
  if(tx_rx_mode == MODE_TX || tx_rx_mode == MODE_QSK_COUNTDOWN)
    last_vbat = analog_read(INPUT_VBAT);
  else {
    // do this every 10th loop. Frequent ADC reads disrupt wifi
    if(i % 100 == 0) {
      update_smeter();
      // Serial.print("[HEAP] ");
      // Serial.println(ESP.getFreeHeap());
      // Serial.println(ESP.getHeapFragmentation());
    }
  }

  // TODO - have some better logic for this, and extract the 2.0v rationality threshold into a settings file
  if (last_vbat > max_vbat || (last_vbat < min_vbat && last_vbat > 2.0)) {
    // turn off TX clock and set VDD off
    gpio_write(OUTPUT_TX_VDD_EN, OUTPUT_OFF);
    my_delay(100);
    si5351.output_enable(SI5351_CLK2, 0);

    Serial.print("[SAFETY] VBat out of range ");
    Serial.println(last_vbat);
    
    set_mode(MODE_RX);
    for (int i = 0; i < 10; i++) {
      gpio_write(OUTPUT_RED_LED, OUTPUT_ON);
      my_delay(50);
      gpio_write(OUTPUT_RED_LED, OUTPUT_OFF);
      my_delay(50);
    }

    // force another ADC read so we don't get stuck in an undervoltage state. Only samples during TX normally.
    last_vbat = analog_read(INPUT_VBAT);
  }

  MDNS.update();
  i++;

  my_delay(25);
}

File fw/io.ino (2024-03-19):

#define ADC_SCALING_VBAT      0.0349
// ADC_SCALING_AUDIO converts ADC counts to volts at the processor pin
#define ADC_SCALING_AUDIO     0.000976

// relay operating time
#define RELAY_DELAY 5

void handle_antenna(WebRequestMethodComposite request_type, AsyncWebServerRequest *request) {
  if(request_type == HTTP_PUT) {
    // look for required parameters in the message
    if(!request->hasParam("antennaPath")) {
      Serial.println("[IO] antennaPath not received");
      request->send(400, "text/plain", "antennaPath not found");
      return;
    }

    String ant_path = request->getParam("antennaPath")->value();

    if(ant_path == "DIRECT")
      ant = OUTPUT_ANT_DIRECT;
    else if(ant_path = "EFHW")
      ant = OUTPUT_ANT_XFMR;
    else {
      request->send(400, "text/plain", "Requested antenna pathway not a valid option");
      return;
    }

    // hardware update will happen through main loop
    flag_freq = true;
    request->send(201, "text/plain", "OK");
  }
  else if(request_type == HTTP_GET) {
    String result;
    if(ant == OUTPUT_ANT_DIRECT)
      result = "DIRECT";
    else if(ant == OUTPUT_ANT_XFMR)
      result = "EFHW";
    
    request->send(200, "text/plain", result);
  }
}


void handle_lna(WebRequestMethodComposite request_type, AsyncWebServerRequest *request) {
  if(request_type == HTTP_PUT) {
    // look for required parameters in the message
    if(!request->hasParam("lnaState")) {
      Serial.println("[IO] lnaState not received");
      request->send(400, "text/plain", "lnaState not found");
      return;
    }

    String lna = request->getParam("lnaState")->value();

    if(lna == "ON")
      lna_state = true;
    else if(lna = "OFF")
      lna_state = false;
    else {
      request->send(400, "text/plain", "Requested LNA state not a valid option");
      return;
    }

    // hardware update will happen through main loop
    flag_freq = true;
    request->send(201, "text/plain", "OK");
  }
  else if(request_type == HTTP_GET) {
    String lna = "";
    if(lna_state)
      lna = "ON";
    else
      lna = "OFF";
    
    request->send(200, "text/plain", lna);
  }
}


// TODO: get rid of hard-coded pin numbering below

void init_gpio() {  
  pinMode(0, OUTPUT);
  pinMode(2, OUTPUT);
  pinMode(15, OUTPUT);
  pinMode(14, OUTPUT);
  pinMode(16, OUTPUT);

  // figure out which hardware version we are running
  hardware_rev = load_json_config(hardware_file, "hardware_rev");

  // set up the relay driver IO expander
  if(!pcf8574_20.begin() && !pcf8574_21.begin())
    Serial.println("[PCF8574] Couldn't initialize");
  else {
    for(int i=0; i < 8; i++) {
      pcf8574_21.write(i, LOW);
      pcf8574_20.write(i, LOW);
    }
    Serial.print("[PCF8574] Connected?: ");
    Serial.print(pcf8574_21.isConnected());
    Serial.print(",");
    Serial.println(pcf8574_20.isConnected());
    Serial.println("[PCF8574] Initialized and set OUTPUT_OFF");
  }

  // turn off LEDs
  gpio_write(OUTPUT_GREEN_LED, OUTPUT_OFF);
  gpio_write(OUTPUT_RED_LED, OUTPUT_OFF);

  // paddle GPIOs
  pinMode(12, INPUT_PULLUP);
  pinMode(13, INPUT_PULLUP);

  // detect key type at startup. straight key will have one pin shorted.
  if(digitalRead(13) == LOW) {
    Serial.println("[KEYER] Straight key detected");
    key = KEY_STRAIGHT;
  }
  else {
    Serial.println("[KEYER] Paddle detected");
    key = KEY_PADDLE;
  }

  // different interrupt actions for different key types
  if(key == KEY_PADDLE)
    attach_paddle_isr(true, true);
  else
    attach_sk_isr(true);

  analogWriteFreq(load_json_config(preference_file, "sidetone_pitch_hz").toInt());

  // select audio filter routing
  gpio_write(OUTPUT_BW_SEL, (output_state) rx_bw);

  // load audio default value
  vol = (uint16_t) load_json_config(preference_file, "af_gain_default").toFloat();
}


// attaches/deattaches interrupt on dit/dah pins
void attach_paddle_isr(bool dit_en, bool dah_en) {
  if(dit_en)
    attachInterrupt(digitalPinToInterrupt(12), paddle_isr, ONLOW);
  if(!dit_en)
    detachInterrupt(digitalPinToInterrupt(12));

  if(dah_en)
    attachInterrupt(digitalPinToInterrupt(13), paddle_isr, ONLOW);
  if(!dah_en)
    detachInterrupt(digitalPinToInterrupt(13));
    
}

// when we detect dit/dah paddle:
//  - turn off the interrupt to prevent future events
//  - set flag so main loop can dit() or dah()
ICACHE_RAM_ATTR void paddle_isr() {
  
  if(!digitalRead(12)) {
    attach_paddle_isr(false, true);
    dit_flag = true;
  }
  if(!digitalRead(13)) {
    attach_paddle_isr(true, false);
    dah_flag = true;
  }
}

// straight key interrupt enable/disable
void attach_sk_isr(bool key_en) {
  if(key_en)
    attachInterrupt(digitalPinToInterrupt(12), sk_isr, CHANGE);
  else
    detachInterrupt(digitalPinToInterrupt(12));    
}

// when we detect key falling:
// - turn off interrupt so key_on() or key_off() can complete before we look again
// - set flag so main loop can act
ICACHE_RAM_ATTR void sk_isr() {  
  // don't listen for interrupts for a bit
  attach_sk_isr(false);

  // check if we need to transition state from UP to DOWN
  if(sk_mode == MODE_SK_UP && digitalRead(12) == 0) {
    Serial.println("key pressed");
    sk_mode = MODE_SK_DOWN;
  }

  // check if we need to transition state from DONW to UP
  if(sk_mode == MODE_SK_DOWN && digitalRead(12) == 1) {
    Serial.println("key released");
    sk_mode = MODE_SK_UP;
  }

  // set a flag for the main loop to act on
  sk_flag = true;
}
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

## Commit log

2023-03-08 rename LEDs, bringing up board
2023-05-12 documentation cleanup
    [body.step, lid.step]
2023-06-05 changes accompanying hardware fixes
    [fw.ino, io.ino, radio.ino]
2023-06-07 prints out signal strength over frequency range
2023-06-20 SOTA spots, plus minor UI fixes
    [keyer.ino, server.ino]
2023-07-30 Web interface updated, minor bugs fixed in api
    [audio.ino, debug.ino, fw.ino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]
2023-07-30 Add licensing, 3d models for case
2023-08-01 fix debug commands, clean up javascript file
    [server.ino]
2023-08-10 new case design including speaker, minor updates
    [MAX-3B_v2 - Lid.stl]
2023-09-19 Documentation update
    [2023-09-18 - MAX-3B Lid.stl, MAX-3B_v2 - Lid.stl]
2023-09-27 docs, and noise test
    [radio.ino, selftest.ino]
2023-09-29 fix some audio bugs
    [audio.ino, digitalModes.ino, fw.ino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]
2023-09-30 fix IP address reporting bug
    [fw.ino, server.ino, wifi.ino]
2023-10-01 fix out of range TX
    [digitalModes.ino, radio.ino]
2023-10-02 fix SSB audio frequency
    [digitalModes.ino, fw.ino, radio.ino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]
2023-11-10 Add 3d model of board
2023-11-26 Add BOM
    Parts list used for build in August 2023
    [2023-08-08 - MAX-3B_2-1 - Parts List for Serial No 10-19.xlsx]
2026-06-15 Fix tuning direction on 20m/40m. Tune to correct sideband by shifting BFO to high end of IF filter.
    [clocks.ino]
